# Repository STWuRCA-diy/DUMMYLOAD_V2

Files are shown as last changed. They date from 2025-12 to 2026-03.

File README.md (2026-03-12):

IMPORTANT!

Unfortunately, I did not have enough time to verify whether the shared version of the board contains any errors. This is a hobby project and I also had to focus on my day job.

I hope someone from the community will be able to review the design, confirm that everything is correct, or fix any mistakes I may have left behind.

The first version of the board did not include many of the components that are present in the shared version. However, all of them were tested using bodge wiring and then added to the shared design.

Good luck!

DUMMYLOAD_V2

High-Voltage Electronic Dummy Load (Non-Commercial, Open-Source)

DUMMYLOAD_V2 is an open-source, non-commercial electronic dummy load designed for testing high-voltage linear power supplies, especially those used in tube (valve) amplifier circuits.

The project includes hardware (PCB), firmware, and mechanical enclosure, forming a complete DIY measurement and load solution for HV power supply development and testing.

Key Features
	•	Adjustable constant-current load
	•	High-voltage measurement via resistor divider
	•	Current measurement using INA219
	•	Protection logic implemented in firmware
	•	Stand-alone operation (no PC required)

Electrical Characteristics
	•	Load mode: Constant Current (CC)
	•	Current regulation range: 0 – ~400 mA (firmware-controlled, step-based)
	•	Voltage measurement

⚠️ HIGH VOLTAGE WARNING

This project is intended for experienced users.

High voltages used in tube power supplies can be lethal.

	•	Use proper insulation and creepage distances
	•	Never touch the circuit during operation
	•	The author assumes no responsibility for misuse

If you are not comfortable working with HV — do not build or use this device.

⸻

📜 License (Very Important)

🔒 Non-Commercial Only

This entire project is licensed under:

Creative Commons Attribution-NonCommercial 4.0 International
(CC BY-NC 4.0)

🍺 Friendly Note

If you ever meet me in person and find this project useful,
you owe me a beer.

If we happen to be in a country where it is legal,
a joint is also acceptable 🙂

This is a friendly gesture — not a legal obligation.

⸻

❤️ Credits

Designed and shared by STWuRCA-diy
DIY spirit, tube amps & open hardware 🤘

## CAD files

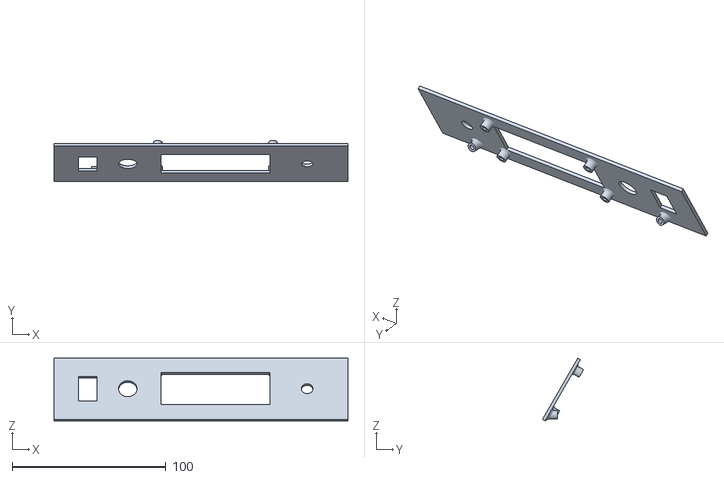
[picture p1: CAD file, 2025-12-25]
3D_MODELS/FRONT.stl
191.2 x 26.8 x 40.8

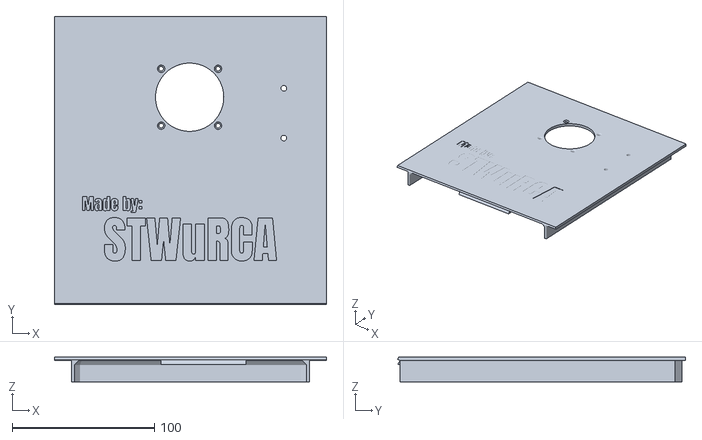
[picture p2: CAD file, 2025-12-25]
3D_MODELS/TOP.stl
191.2 x 202.5 x 17.5

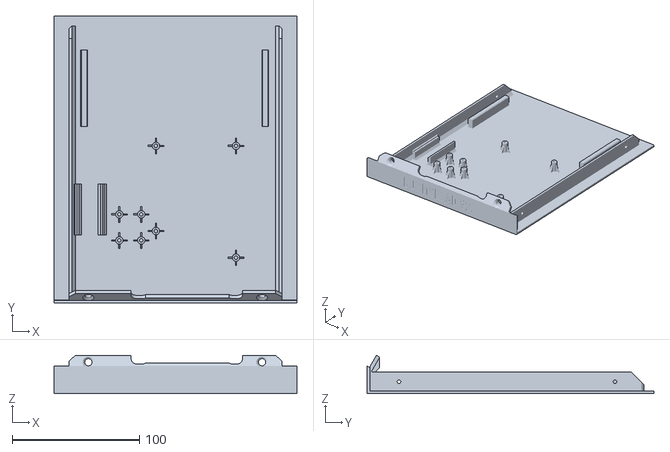
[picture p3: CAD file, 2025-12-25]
3D_MODELS/BOTTOM.stl
191.2 x 225.5 x 30.3

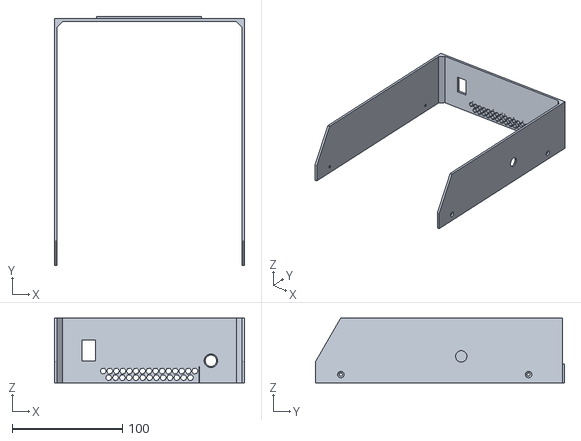
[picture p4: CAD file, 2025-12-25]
3D_MODELS/FRAME.stl
172.2 x 225.5 x 58.6

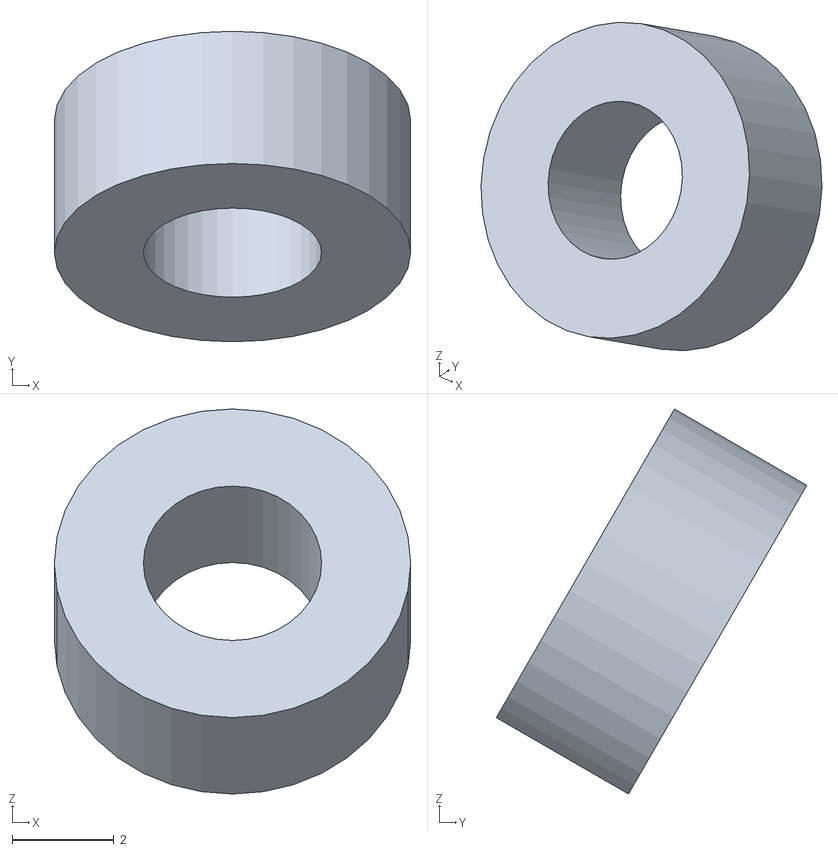
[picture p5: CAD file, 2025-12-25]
3D_MODELS/WASHER_LCD.stl
7.00 x 6.10 x 7.56

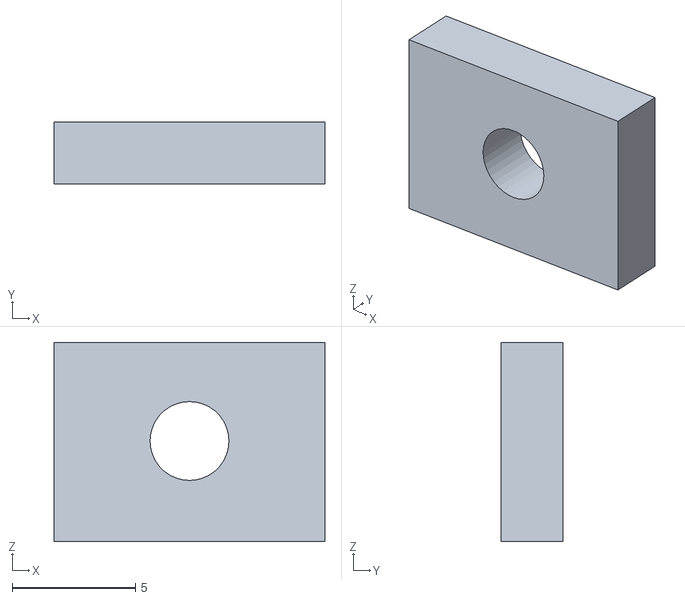
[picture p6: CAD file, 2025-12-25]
3D_MODELS/WASHER_FRONT.stl
11.0 x 2.50 x 8.08

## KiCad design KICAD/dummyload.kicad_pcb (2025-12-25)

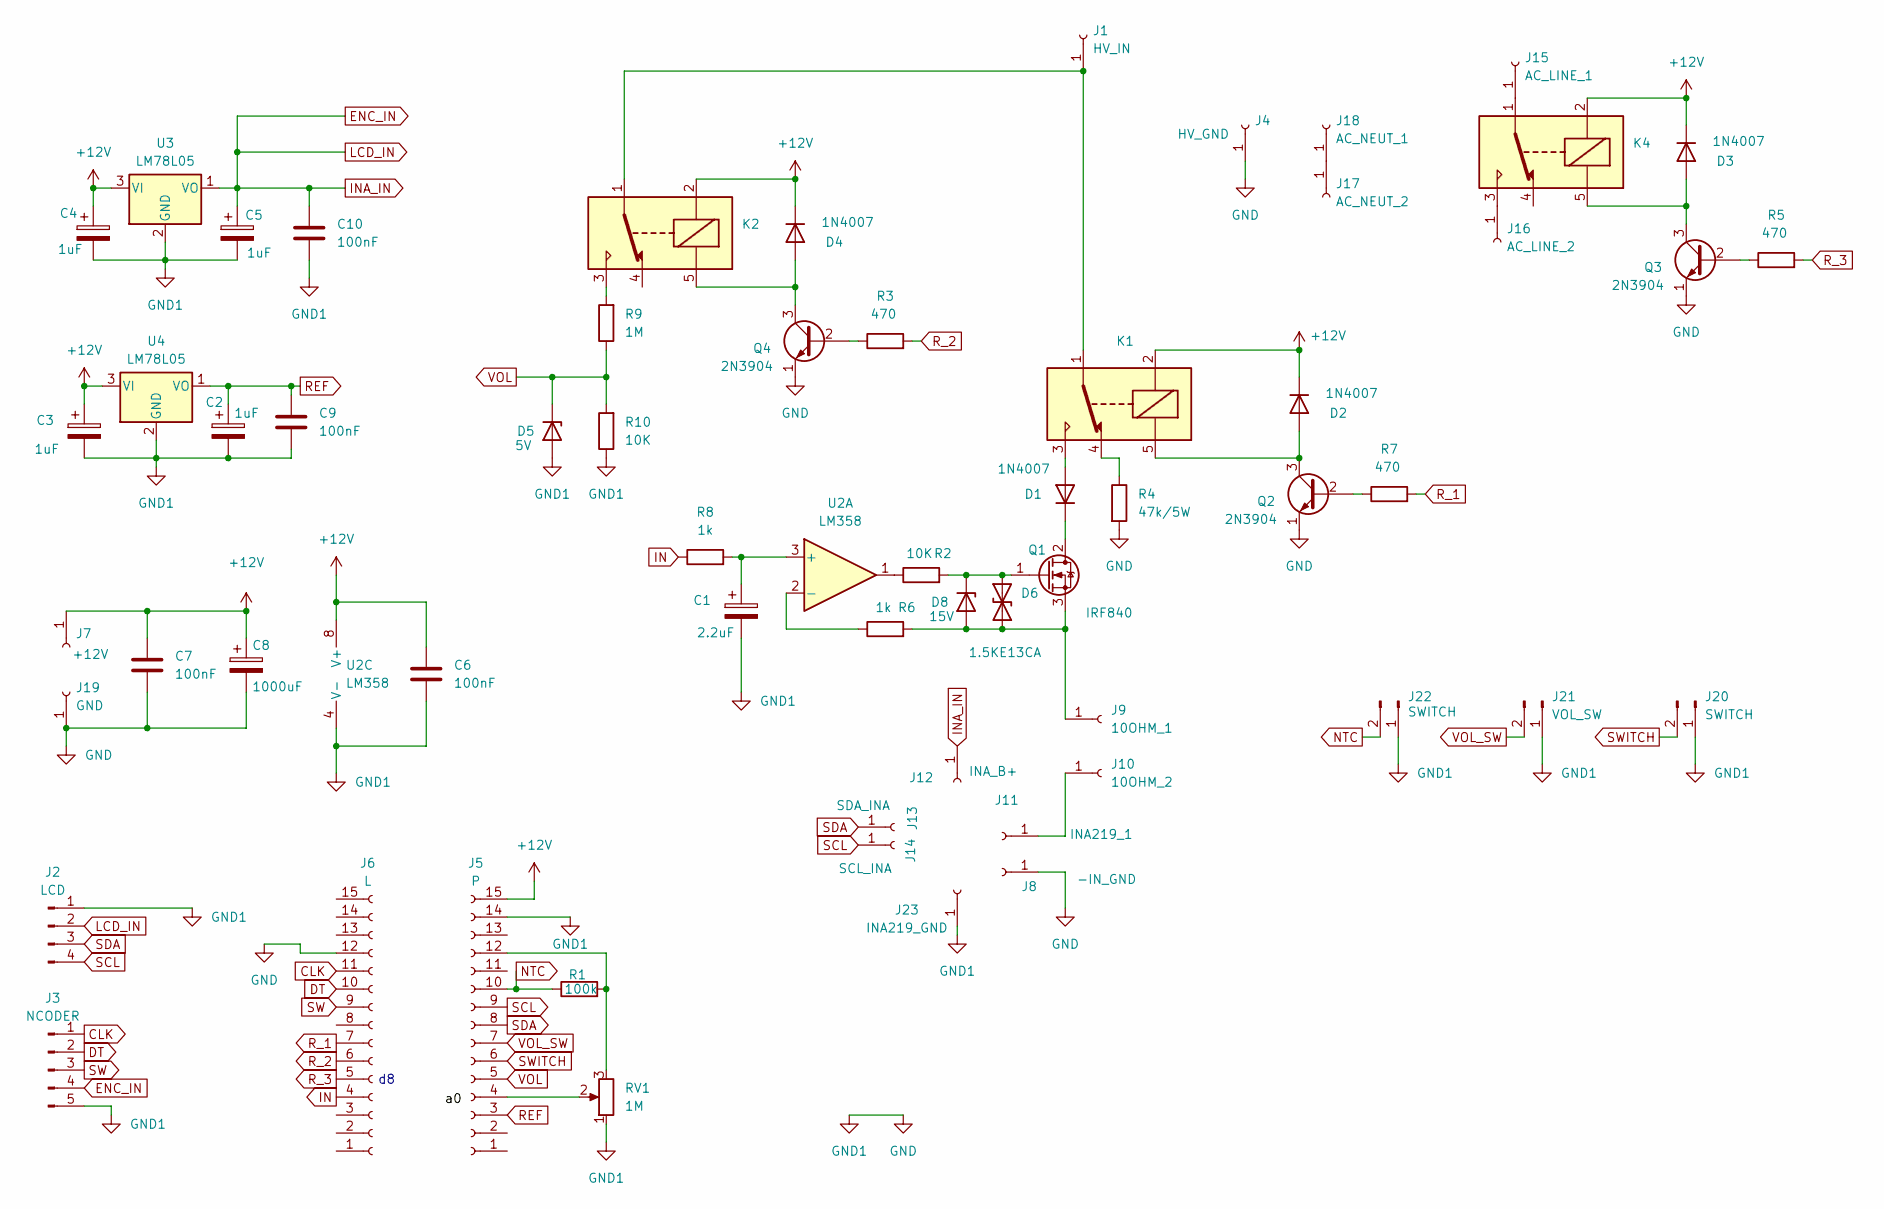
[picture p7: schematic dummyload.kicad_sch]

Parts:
C1: 2.2uF; CP_Radial_D4.0mm_P2.00mm
C2, C3, C4, C5: 1uF; CP_Radial_D4.0mm_P2.00mm
C6, C7, C9, C10: 100nF; C_Disc_D3.0mm_W2.0mm_P2.50mm
C8: 1000uF; CP_Radial_D8.0mm_P5.00mm
D1, D2, D3, D4: 1N4007; D_DO-41_SOD81_P10.16mm_Horizontal
D5: 5V; D_A-405_P7.62mm_Horizontal
D6: 1.5KE13CA; D_DO-41_SOD81_P10.16mm_Horizontal
D8: 15V; D_A-405_P10.16mm_Horizontal
J1: HV_IN; SolderWire-0.5sqmm_1x01_D0.9mm_OD2.1mm
J2: LCD; PinHeader_1x04_P2.54mm_Vertical
J3: NCODER; PinHeader_1x05_P2.54mm_Vertical
J4: HV_GND; SolderWire-0.5sqmm_1x01_D0.9mm_OD2.1mm
J5: P; PinHeader_1x15_P2.54mm_Vertical
J6: L; PinHeader_1x15_P2.54mm_Vertical
J7: +12V; SolderWire-0.5sqmm_1x01_D0.9mm_OD2.1mm
J8: -IN_GND; SolderWire-0.5sqmm_1x01_D0.9mm_OD2.1mm
J9: 10OHM_1; SolderWire-0.5sqmm_1x01_D0.9mm_OD2.1mm
J10: 10OHM_2; SolderWire-0.5sqmm_1x01_D0.9mm_OD2.1mm
J11: INA219_1; SolderWire-0.5sqmm_1x01_D0.9mm_OD2.1mm
J12: INA_B+; SolderWire-0.5sqmm_1x01_D0.9mm_OD2.1mm
J13: SDA_INA; SolderWire-0.5sqmm_1x01_D0.9mm_OD2.1mm
J14: SCL_INA; SolderWire-0.5sqmm_1x01_D0.9mm_OD2.1mm
J15: AC_LINE_1; SolderWire-0.5sqmm_1x01_D0.9mm_OD2.1mm
J16: AC_LINE_2; SolderWire-0.5sqmm_1x01_D0.9mm_OD2.1mm
J17: AC_NEUT_2; SolderWire-0.5sqmm_1x01_D0.9mm_OD2.1mm
J18: AC_NEUT_1; SolderWire-0.5sqmm_1x01_D0.9mm_OD2.1mm
J19: GND; SolderWire-0.5sqmm_1x01_D0.9mm_OD2.1mm
J20, J22: SWITCH; PinHeader_1x02_P2.54mm_Vertical
J21: VOL_SW; PinHeader_1x02_P2.54mm_Vertical
J23: INA219_GND; SolderWire-0.5sqmm_1x01_D0.9mm_OD2.1mm
K1, K2, K4: SANYOU_SRD_Form_C; Relay_SPDT_SANYOU_SRD_Series_Form_C
Q1: IRF840; TO-220-3_Vertical
Q2, Q3, Q4: 2N3904; TO-92_Inline
R1: 100k; R_Axial_DIN0207_L6.3mm_D2.5mm_P10.16mm_Horizontal
R2, R10: 10K; R_Axial_DIN0207_L6.3mm_D2.5mm_P10.16mm_Horizontal
R3, R5, R7: 470; R_Axial_DIN0207_L6.3mm_D2.5mm_P10.16mm_Horizontal
R4: 47k/5W; R_Axial_DIN0309_L9.0mm_D3.2mm_P12.70mm_Horizontal
R6, R8: 1k; R_Axial_DIN0207_L6.3mm_D2.5mm_P10.16mm_Horizontal
R9: 1M; R_Axial_DIN0207_L6.3mm_D2.5mm_P10.16mm_Horizontal
RV1: 1M; Potentiometer_Vishay_T73YP_Vertical
U2: LM358; CERDIP-8_W7.62mm_SideBrazed
U3, U4: LM78L05; TO-92_Inline

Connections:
+12V: C3.1, C4.1, C6.1, C7.1, C8.1, D2.1 (K), D3.1 (K), D4.1 (K), J5.15, J7.1, K1.2, K2.2, K4.2, U2.8 (V+), U3.3 (VI), U4.3 (VI)
CLK: J3.1, J6.11
DT: J3.2, J6.10
ENC_IN: C5.1, C10.1, J2.2, J3.4, J12.1, U3.1 (VO)
GND: C1.2, C2.2, C3.2, C4.2, C5.2, C6.2, C7.2, C8.2, C9.2, C10.2, D5.2 (A), J2.1, J3.5, J4.1, J5.14, J6.12, J8.1, J19.1, J20.1, J21.1, J22.1, J23.1, Q2.1 (E), Q3.1 (E), Q4.1 (E), R4.2, R10.1, RV1.1, U2.4 (V-), U3.2 (GND), U4.2 (GND)
IN: J6.4, R8.1
NTC: J5.10, J22.2, R1.1
unnamed: D1.2 (A), K1.3
unnamed: D1.1 (K), Q1.2 (D)
unnamed: D2.2 (A), K1.5, Q2.3 (C)
unnamed: D3.2 (A), K4.5, Q3.3 (C)
unnamed: D4.2 (A), K2.5, Q4.3 (C)
unnamed: D6.1 (A1), D8.1 (K), Q1.1 (G), R2.2
unnamed: D6.2 (A2), D8.2 (A), J9.1, Q1.3 (S), R6.2
unnamed: J1.1, K1.1, K2.1
unnamed: J5.4, RV1.2
unnamed: J5.12, R1.2, RV1.3
unnamed: J10.1, J11.1
unnamed: J15.1, K4.1
unnamed: J16.1, K4.3
unnamed: J17.1, J18.1
unnamed: K1.4, R4.1
unnamed: K2.3, R9.2
unnamed: Q2.2 (B), R7.1
unnamed: Q3.2 (B), R5.1
unnamed: Q4.2 (B), R3.1
unnamed: R2.1, U2.1
unnamed: C1.1, R8.2, U2.3 (+)
unnamed: R6.1, U2.2 (-)
REF: C2.1, C9.1, J5.3, U4.1 (VO)
R_1: J6.7, R7.2
R_2: J6.6, R3.2
R_3: J6.5, R5.2
SCL: J2.4, J5.9, J14.1
SDA: J2.3, J5.8, J13.1
SW: J3.3, J6.9
SWITCH: J5.6, J20.2
VOL: D5.1 (K), J5.5, R9.1, R10.2
VOL_SW: J5.7, J21.2

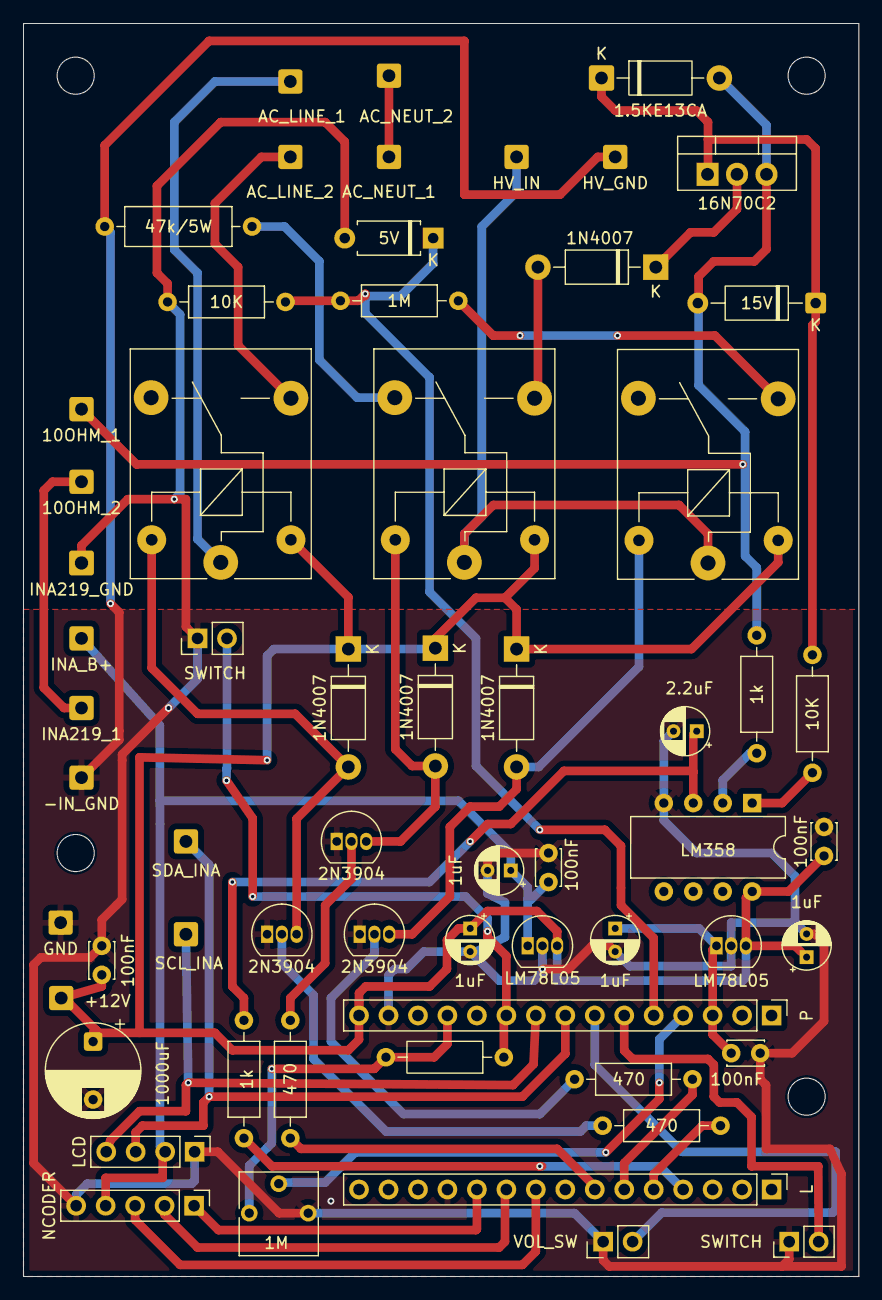
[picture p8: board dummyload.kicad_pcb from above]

Board: 2 copper layers, 72.0 x 108.0 mm, 61 parts (0 on the bottom side), 39 nets.

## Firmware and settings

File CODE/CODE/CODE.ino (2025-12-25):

#include <Wire.h>
#include <Adafruit_INA219.h>
#include <LiquidCrystal_I2C.h>
#include <math.h>

float cachedCurrent = 0.0;
unsigned long lastCurrentRead = 0;

float cachedVoltage = 0.0;
unsigned long lastVoltageRead = 0;

String lastLine0 = "";
String lastLine1 = "";


// Ekran powitalny
const unsigned long WELCOME_CHAR_DELAY   = 160;  
const unsigned long WELCOME_BY_DELAY     = 800;   
const unsigned long WELCOME_AUTHOR_DELAY = 1200; 

// Sekwencje D6/D8
const unsigned long SEQUENCE_D6_ENABLE_TIME  = 400;  
const unsigned long SEQUENCE_D8_ENABLE_TIME  = 525;  
const unsigned long SEQUENCE_D6_DISABLE_TIME = 600;  

// Timery systemowe
const unsigned long ENCODER_DELAY           = 50;   
const unsigned long DEBOUNCE_DELAY          = 25;   
const unsigned long DISPLAY_UPDATE_INTERVAL = 100; 
const unsigned long VOLTAGE_UPDATE_INTERVAL = 400; 
const unsigned long CONTROL_UPDATE_INTERVAL = 5;  
const unsigned long MAIN_LOOP_DELAY         = 1;    
const unsigned long ERROR_LOOP_DELAY        = 30;   

Adafruit_INA219 ina219;

LiquidCrystal_I2C lcd(0x27, 16, 2);

int encoderPinCLK      = 2;   
int encoderPinDT       = 3;   
int encoderSW          = 4;   
int enablePin          = A2; 
int sequencePin1       = 6;   
int sequencePin2       = 8;  
int relayPin           = 7;   
int voltagePin         = A1;  
int voltageSwitchPin   = A3;  
const int calibrationPin = A0; 
const int pwmPin       = 9;   

float desiredCurrent = 0.0;   
int   pwmValue       = 0;     
float pwmAccumulator = 0.0;   

volatile bool encoderChanged   = false;
volatile int  encoderDirection = 0;
volatile uint8_t lastCLK;


unsigned long lastEncoderChange = 0;

bool pwmEnabled = false;

bool lastEnableButtonState     = HIGH;
bool currentEnableButtonState  = HIGH;
bool lastEncoderButtonState    = HIGH;
bool currentEncoderButtonState = HIGH;
unsigned long lastDebounceTime          = 0;
unsigned long lastEncoderButtonDebounce = 0;

bool lastVoltageSwitchState      = HIGH;
bool currentVoltageSwitchState   = HIGH;
unsigned long lastVoltageSwitchDebounce = 0;
bool voltageDividerEnabled       = false;
bool safetyLockActive            = false;  
bool overTempLockout             = false; 
const float SAFETY_VOLTAGE_THRESHOLD = 10.0; 

unsigned long enableStartTime  = 0;
unsigned long pin1EnableTime   = 0;   
unsigned long disableStartTime = 0;  
bool enableSequenceActive      = false;
bool disableSequenceActive     = false;
bool pin1EnableDone            = false; 
bool pin2EnableDone            = false; 
bool pin1DisableDone           = false; 

const float MAX_VOLTAGE = 4.5; 

const float CURRENT_STEP = 10.0; 
const float MAX_CURRENT  = 400.0;

const float FILTER_R   = 1000.0;
const float FILTER_C   = 2.2e-6;
const float FILTER_TAU = FILTER_R * FILTER_C;

const float AREF_VOLTAGE   = 5.0;
const int   PWM_RESOLUTION = 255; 
const float VOLTAGE_PER_PWM = AREF_VOLTAGE / PWM_RESOLUTION;

const int CURRENT_SAMPLES = 5;
float currentBuffer[CURRENT_SAMPLES] = {0};
int   currentIndex = 0;

const int VOLTAGE_SAMPLES = 8;
float voltageBuffer[VOLTAGE_SAMPLES] = {0};
int   voltageIndex = 0;

unsigned long lastDisplayUpdate = 0;

unsigned long lastVoltageUpdate = 0;
float displayVoltage = 0.0;
float displayPower   = 0.0;

const float DEAD_ZONE    = 1.0;  
const float MAX_PWM_STEP = 0.5;  
const float CONTROL_GAIN = 0.06;
unsigned long lastControlUpdate = 0;

const int NUM_CALIBRATION_POINTS = 9;

struct CalibrationPoint {
    float voltage;
    float current;
} calibration[NUM_CALIBRATION_POINTS] = {
    {0.0,  0},
    {0.1,  10.0},
    {0.2,  20.0},
    {0.3,  30.0},
    {0.4,  40.0},
    {1.0,  100.0},
    {2.0,  200.0},
    {3.0,  300.0},
    {4.0,  400.0},
};

float getFilteredCurrent() {
    float newCurrent = ina219.getCurrent_mA();
    if (newCurrent < 0) newCurrent = 0.0;

    currentBuffer[currentIndex] = newCurrent;
    currentIndex = (currentIndex + 1) % CURRENT_SAMPLES;

    float sum = 0.0;
    for (int i = 0; i < CURRENT_SAMPLES; i++) {
        sum += currentBuffer[i];
    }
    float avg = sum / CURRENT_SAMPLES;

    static bool  initialized = false;
    static float filtered    = 0.0;

    if (!initialized) {
        filtered    = avg;
        initialized = true;
        return filtered;
    }

    const float alpha = 0.25; 
    float candidate = filtered * (1.0 - alpha) + avg * alpha;

    const float MAX_DELTA = 5.0; 
    float delta = candidate - filtered;
    if (delta > MAX_DELTA)      delta = MAX_DELTA;
    else if (delta < -MAX_DELTA) delta = -MAX_DELTA;

    filtered += delta;
    return filtered;
}

float getFilteredVoltageA1() {
    int rawHV = analogRead(voltagePin);
    float hvBase = (rawHV / 1023.0) * AREF_VOLTAGE;
    hvBase *= 100.0;

    int rawCal = analogRead(calibrationPin);
    float vCal = (rawCal / 1023.0) * AREF_VOLTAGE;

    const float MIN_GAIN = 0.9167;
    const float MAX_GAIN = 1.0833;

    float gain = MIN_GAIN + (vCal / AREF_VOLTAGE) * (MAX_GAIN - MIN_GAIN);

    // Zastosuj kalibrację
    float hvCalibrated = hvBase * gain;

    voltageBuffer[voltageIndex] = hvCalibrated;
    voltageIndex = (voltageIndex + 1) % VOLTAGE_SAMPLES;

    float sum = 0.0;
    for (int i = 0; i < VOLTAGE_SAMPLES; i++) {
        sum += voltageBuffer[i];
    }
    return sum / VOLTAGE_SAMPLES;
}

float getDesiredCurrentForVoltage(float voltage) {
    float rawCurrent = 0.0;

    for (int i = 0; i < NUM_CALIBRATION_POINTS - 1; i++) {
        if (voltage >= calibration[i].voltage && voltage < calibration[i+1].voltage) {
            float slope = (calibration[i+1].current - calibration[i].current) /
                          (calibration[i+1].voltage - calibration[i].voltage);
            rawCurrent = calibration[i].current + slope * (voltage - calibration[i].voltage);
            break;
        }
    }

    return round(rawCurrent / 10.0) * 10.0;
}

void encoderISR() {
    int currentCLK = digitalRead(encoderPinCLK);

    if (currentCLK != lastCLK) {
        if (digitalRead(encoderPinDT) != currentCLK) {
            encoderDirection = 1;
        } else {
            encoderDirection = -1;
        }
        encoderChanged = true;
    }
    lastCLK = currentCLK;
}
void updateCurrentMeasurement() {
    if (millis() - lastCurrentRead >= CONTROL_UPDATE_INTERVAL) {
        cachedCurrent = getFilteredCurrent();
        lastCurrentRead = millis();
    }
}

void updateVoltageMeasurement() {
    if (millis() - lastVoltageRead >= VOLTAGE_UPDATE_INTERVAL) {
        cachedVoltage = getFilteredVoltageA1();
        lastVoltageRead = millis();
    }
}

void handleEnableButton() {
    int reading = digitalRead(enablePin);

    if (reading != lastEnableButtonState) {
        lastDebounceTime = millis();
    }

    if ((millis() - lastDebounceTime) > DEBOUNCE_DELAY) {
        if (reading != currentEnableButtonState) {
            currentEnableButtonState = reading;

            if (currentEnableButtonState == LOW) {
                if (!pwmEnabled && safetyLockActive) {
                    return;
                }
                if (!pwmEnabled && overTempLockout) {
                    return;
                }
                if (!pwmEnabled && desiredCurrent == 0) {
                    return;
                }

                pwmEnabled = !pwmEnabled;

                if (pwmEnabled) {
                    if (desiredCurrent > 0) {
                        enableStartTime      = millis();
                        enableSequenceActive = true;
                        pin1EnableDone       = false;
                        pin2EnableDone       = false;
                    }
                } else {
                    pwmValue       = 0;
                    pwmAccumulator = 0.0;
                    noInterrupts();
                    OCR1A = 0;
                    interrupts();

                    digitalWrite(sequencePin2, LOW);

                    disableStartTime      = millis();
                    disableSequenceActive = true;
                    pin1DisableDone       = false;

                    enableSequenceActive = false;
                }
            }
        }
    }

    lastEnableButtonState = reading;
}

void handleEncoderButton() {
    int reading = digitalRead(encoderSW);

    if (reading != lastEncoderButtonState) {
        lastEncoderButtonDebounce = millis();
    }

    if ((millis() - lastEncoderButtonDebounce) > DEBOUNCE_DELAY) {
        if (reading != currentEncoderButtonState) {
            currentEncoderButtonState = reading;

            if (currentEncoderButtonState == LOW && !pwmEnabled) {
                desiredCurrent = 0.0;
            }
        }
    }

    lastEncoderButtonState = reading;
}

void handleEncoder() {
    if (pwmEnabled) {
        encoderChanged = false;
        return;
    }

    if (encoderChanged) {
        if ((millis() - lastEncoderChange) >= ENCODER_DELAY) {
            desiredCurrent += encoderDirection * CURRENT_STEP;
            desiredCurrent  = constrain(desiredCurrent, 0.0, MAX_CURRENT);
            lastEncoderChange = millis();
        }
        encoderChanged = false;
    }
}

int calculatePWM(float voltage) {
    float pwmFloat = (voltage / AREF_VOLTAGE) * PWM_RESOLUTION;
    int pwm = round(pwmFloat);
    return constrain(pwm, 0, 255);
}

float calculateVoltage(int pwm) {
    return (pwm * VOLTAGE_PER_PWM);
}

void handleVoltageDividerSwitch() {
    int reading = digitalRead(voltageSwitchPin);

    if (reading != lastVoltageSwitchState) {
        lastVoltageSwitchDebounce = millis();
    }

    if ((millis() - lastVoltageSwitchDebounce) > DEBOUNCE_DELAY) {
        if (reading != currentVoltageSwitchState) {
            currentVoltageSwitchState = reading;
        }
    }

    lastVoltageSwitchState = reading;

    float currentVoltage = cachedVoltage;

    bool dividerShouldBeOn = true;

    if (pwmEnabled) {
        dividerShouldBeOn = (currentVoltageSwitchState == LOW);
        safetyLockActive  = false;
    } else {
        dividerShouldBeOn = true;

        if (currentVoltage >= SAFETY_VOLTAGE_THRESHOLD) {
            safetyLockActive = true;
        } else {
            safetyLockActive = false;
        }
    }

    digitalWrite(relayPin, dividerShouldBeOn ? HIGH : LOW);
    voltageDividerEnabled = dividerShouldBeOn;
}

void precisionCurrentControl() {
    if (!pwmEnabled) return;
    if (!pin2EnableDone) return;

    if ((millis() - lastControlUpdate) < CONTROL_UPDATE_INTERVAL) {
        return;
    }
    lastControlUpdate = millis();

    float currentCurrent = cachedCurrent;
    float error          = desiredCurrent - currentCurrent;

    if (abs(error) <= DEAD_ZONE) {
        return;
    }

    float correction = error * CONTROL_GAIN;
    float maxStep    = (abs(error) > 15.0) ? MAX_PWM_STEP * 1.2 : MAX_PWM_STEP;

    if (correction > maxStep)       correction = maxStep;
    else if (correction < -maxStep) correction = -maxStep;

    pwmAccumulator += correction;
    pwmAccumulator = constrain(pwmAccumulator, 0.0, 255.0);

    pwmValue = (int)round(pwmAccumulator);
    noInterrupts();
    OCR1A = pwmValue;
    interrupts();
}

void handleSequenceTimers() {
    unsigned long currentTime = millis();

    if (enableSequenceActive) {
        if (!pin1EnableDone && (currentTime - enableStartTime >= SEQUENCE_D6_ENABLE_TIME)) {
            digitalWrite(sequencePin1, HIGH);
            pin1EnableDone = true;
            pin1EnableTime = currentTime;
        }

        if (pin1EnableDone && !pin2EnableDone && (currentTime - pin1EnableTime >= SEQUENCE_D8_ENABLE_TIME)) {
            digitalWrite(sequencePin2, HIGH);
            pin2EnableDone       = true;
            enableSequenceActive = false;
        }
    }

    if (disableSequenceActive) {
        if (!pin1DisableDone && (currentTime - disableStartTime >= SEQUENCE_D6_DISABLE_TIME)) {
            digitalWrite(sequencePin1, LOW);
            pin1DisableDone       = true;
            disableSequenceActive = false;
        }
    }
}

const int ntcPin = A6;

const float NTC_SERIES_RESISTOR      = 100000.0;
const float NTC_NOMINAL_RESISTANCE   = 100000.0;
const float NTC_NOMINAL_TEMPERATURE  = 25.0;
const float NTC_BETA_COEFFICIENT     = 3950.0; 
const float NTC_SHUTDOWN_TEMPERATURE = 50.0;  
const float NTC_RESET_TEMPERATURE    = 40.0; 

float readNtcTemperatureC() {
    int adc = analogRead(ntcPin);
    if (adc <= 0 || adc >= 1023) {
        return 150.0;
    }

    float resistance = NTC_SERIES_RESISTOR * ((float)adc / (1023.0 - (float)adc));

    // Steinhart–Hart (wersja uproszczona z B-eta)
    float steinhart = resistance / NTC_NOMINAL_RESISTANCE; 
    steinhart = log(steinhart); 
    steinhart /= NTC_BETA_COEFFICIENT; 
    steinhart += 1.0 / (NTC_NOMINAL_TEMPERATURE + 273.15); 
    steinhart = 1.0 / steinhart;
    steinhart -= 273.15;  

    return steinhart;
}

void thermalShutdownDisableLoad() {
    if (!pwmEnabled) return; 

    pwmEnabled      = false;
    pwmValue        = 0;
    pwmAccumulator  = 0.0;
    noInterrupts();
    OCR1A = 0;
    interrupts();

    digitalWrite(sequencePin2, LOW);

    disableStartTime      = millis();
    disableSequenceActive = true;
    pin1DisableDone       = false;

    enableSequenceActive = false;
}

void handleTemperatureProtection() {
    static unsigned long lastTempRead = 0;
    const unsigned long TEMP_READ_INTERVAL = 500;

    unsigned long now = millis();
    if (now - lastTempRead < TEMP_READ_INTERVAL) {
        return;
    }
    lastTempRead = now;

    float tempC = readNtcTemperatureC();

    if (tempC >= NTC_SHUTDOWN_TEMPERATURE) {
        if (pwmEnabled) {
            thermalShutdownDisableLoad();
        }
        overTempLockout = true;
    }
    else if (overTempLockout && tempC <= NTC_RESET_TEMPERATURE) {
        overTempLockout = false;
    }
}

void updateDisplay();

void setup() {
    Serial.begin(9600);
    Wire.begin();

    lcd.init();
    lcd.backlight();
    lcd.clear();

    String welcomeText = "DUMMYLOAD V2";
    int startPos = 2;

    lcd.setCursor(startPos, 0);
    for (int i = 0; i < welcomeText.length(); i++) {
        lcd.print(welcomeText.charAt(i));
        delay(WELCOME_CHAR_DELAY);
    }

    lcd.setCursor(2, 1);
    lcd.print("by:");
    delay(WELCOME_BY_DELAY);
    lcd.print(" STWuRCA");

    delay(WELCOME_AUTHOR_DELAY);
    lcd.clear();

    analogReference(EXTERNAL);

    if (!ina219.begin()) {
        lcd.clear();
        lcd.print("BLAD INA219!");
        lcd.setCursor(0, 1);
        lcd.print("Sprawdz podlacz");
        while (1) { delay(ERROR_LOOP_DELAY); }
    }

    // Konfiguracja pinów
    pinMode(pwmPin, OUTPUT);
    pinMode(encoderPinCLK, INPUT_PULLUP);
    pinMode(encoderPinDT, INPUT_PULLUP);
    pinMode(encoderSW, INPUT_PULLUP);
    pinMode(enablePin, INPUT_PULLUP);
    pinMode(calibrationPin, INPUT);

    pinMode(sequencePin1, OUTPUT);
    pinMode(sequencePin2, OUTPUT);
    pinMode(relayPin, OUTPUT);
    pinMode(voltagePin, INPUT);
    pinMode(voltageSwitchPin, INPUT_PULLUP);

    digitalWrite(sequencePin1, LOW);
    digitalWrite(sequencePin2, LOW);
    digitalWrite(relayPin, LOW);
    updateCurrentMeasurement();
    updateVoltageMeasurement();

    for (int i = 0; i < CURRENT_SAMPLES; i++) currentBuffer[i]  = 0.0;
    for (int i = 0; i < VOLTAGE_SAMPLES; i++) voltageBuffer[i] = 0.0;

    lastEnableButtonState     = digitalRead(enablePin);
    currentEnableButtonState  = lastEnableButtonState;
    lastEncoderButtonState    = digitalRead(encoderSW);
    currentEncoderButtonState = lastEncoderButtonState;
    lastVoltageSwitchState    = digitalRead(voltageSwitchPin);
    currentVoltageSwitchState = lastVoltageSwitchState;
    lastCLK = PIND & (1 << 2);

    attachInterrupt(digitalPinToInterrupt(encoderPinCLK), encoderISR, CHANGE);
    float initI = ina219.getCurrent_mA();
    for (int i = 0; i < CURRENT_SAMPLES; i++) currentBuffer[i] = initI;

    float initV = cachedVoltage;
    for (int i = 0; i < VOLTAGE_SAMPLES; i++) voltageBuffer[i] = initV;

    TCCR1A = 0;
    TCCR1B = 0;

    TCCR1A |= (1 << WGM10);         
    TCCR1B |= (1 << WGM12);  

    TCCR1A |= (1 << COM1A1); 
    TCCR1B |= (1 << CS11);   

    noInterrupts();
    OCR1A = 0;
    interrupts(); 

    pwmValue           = 0;
    pwmAccumulator     = 0.0;
    voltageDividerEnabled = false;
    safetyLockActive      = false;
    overTempLockout       = false;
}

void loop() {
    updateCurrentMeasurement();
    updateVoltageMeasurement();

    handleEnableButton();
    handleEncoderButton();
    handleVoltageDividerSwitch();
    handleEncoder();
    handleSequenceTimers();
    precisionCurrentControl();
    handleTemperatureProtection();

    if ((millis() - lastDisplayUpdate) >= DISPLAY_UPDATE_INTERVAL) {
        updateDisplay();
        lastDisplayUpdate = millis();
    }

    delay(MAIN_LOOP_DELAY);
}

void updateDisplay() {
    float currentCurrent = cachedCurrent;

    if ((millis() - lastVoltageUpdate) >= VOLTAGE_UPDATE_INTERVAL) {
        displayVoltage = getFilteredVoltageA1();

        if (voltageDividerEnabled && pwmEnabled) {
            displayPower = (displayVoltage * currentCurrent);
        } else {
            displayPower = 0.0;
        }

        lastVoltageUpdate = millis();
    }

    String newLine0 = "Set:";
    newLine0 += String((int)desiredCurrent);
    newLine0 += "mA ";

    int voltageStartPos = newLine0.length();
    newLine0 += String((int)displayVoltage);
    newLine0 += "V";

    while (newLine0.length() < 15) newLine0 += " ";
    newLine0 += pwmEnabled ? "E" : "D";

    String newLine1 = "I:";
    newLine1 += String((int)currentCurrent);
    newLine1 += "mA";

    int powerStartPos = voltageStartPos;
    if (powerStartPos <= newLine1.length()) {
        powerStartPos = newLine1.length() + 1;
    }
    while (newLine1.length() < powerStartPos) newLine1 += " ";

    if (voltageDividerEnabled && pwmEnabled) {
        if (displayPower < 1000.0) {
            newLine1 += String((int)displayPower);
            newLine1 += "mW";
        } else {
            newLine1 += String((int)(displayPower / 1000.0));
            newLine1 += "W";
        }
    }

    if (newLine0.length() > 16) newLine0 = newLine0.substring(0, 16);
    if (newLine1.length() > 16) newLine1 = newLine1.substring(0, 16);
    while (newLine0.length() < 16) newLine0 += " ";
    while (newLine1.length() < 16) newLine1 += " ";

    if (newLine0 != lastLine0) {
        lcd.setCursor(0, 0);
        lcd.print(newLine0);
        lastLine0 = newLine0;
    }

    if (newLine1 != lastLine1) {
        lcd.setCursor(0, 1);
        lcd.print(newLine1);
        lastLine1 = newLine1;
    }
}
